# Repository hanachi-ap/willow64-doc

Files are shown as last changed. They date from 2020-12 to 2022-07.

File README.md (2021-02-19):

# willow64-doc
 In Japanese docments: [日本語での説明はこちら](README_JP.md)

## About Willow64 keyboard

The Willow64 is a split-type self-made keyboard featuring a key arrangement that gently fits natural finger movements.

Detailed article - [Introductory about Willow 64](https://coal.hatenablog.com/entry/2020/12/04/231923)

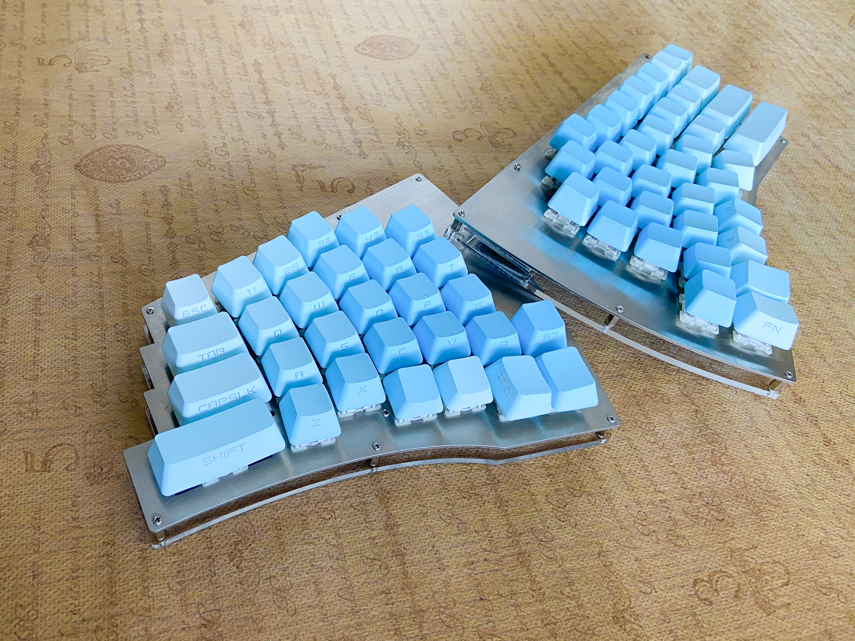
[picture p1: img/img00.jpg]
Willow64 willow64 keyboard
  

## Build guide

 [Willow64 keyboard Build guide](buildguide-willow64-r2.md)  (in Japanese) 

## QMK firmware

#### GitHub
  
  https://github.com/hanachi-ap/qmk_firmware/tree/willow64

#### QMK Firmware binary files.

  - [Default keymap (VIA enabled)](https://github.com/hanachi-ap/willow64-doc/releases/download/rev2.3.1/willow_willow64_via_default.hex)

    -  [Description about default keymap](./default-keymap.md)

  - [Test keymap](https://github.com/hanachi-ap/willow64-doc/releases/download/rev2.3.1/willow_willow64_buildtest.hex)

  - [Author's custom keymap](https://github.com/hanachi-ap/willow64-doc/releases/download/rev2.3.1/willow_willow64_via_hanachi.hex)

#### VIA json file

  - [VIA-wllow64.json](https://github.com/hanachi-ap/willow64-doc/releases/download/rev2.3.1/VIA_keymap_wllow64.json)

## Willow Layout

Willow Layout is open for the community to grow.
It is available under the Creative Commons license.

 [Willow Layout (PDF)](https://github.com/hanachi-ap/willow64-doc/blob/main/img/willow_layout_v1.pdf)  CC BY-SA 4.0 by Hanachi.

- For checking the layout before purchasing a product.
- For your new product development.
- For various research.

Feedback to the author would be a pleasure.

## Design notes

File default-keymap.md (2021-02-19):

# Description about default keymap

### layer 0 -- QWERTY layer

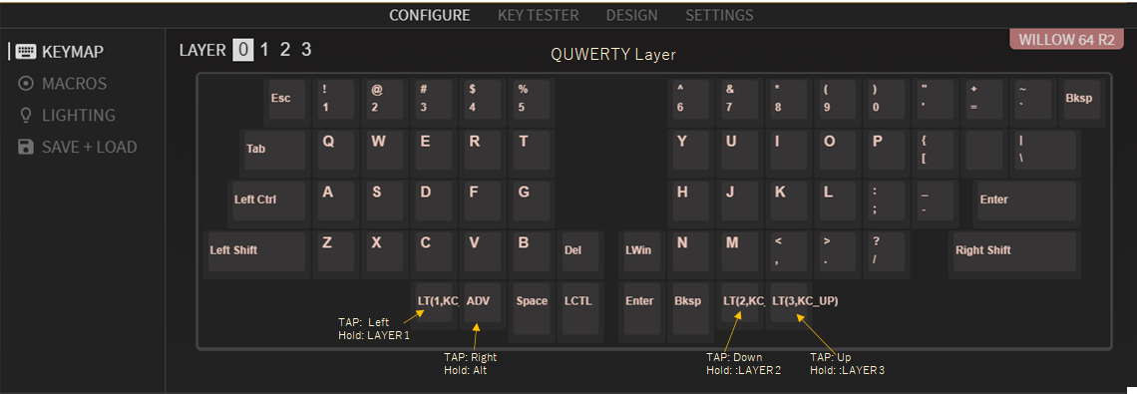
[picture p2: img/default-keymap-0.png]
Default keymap layer 0 Default keymap layer 0: QWERTY
  

### layer 1 -- Numpad layer

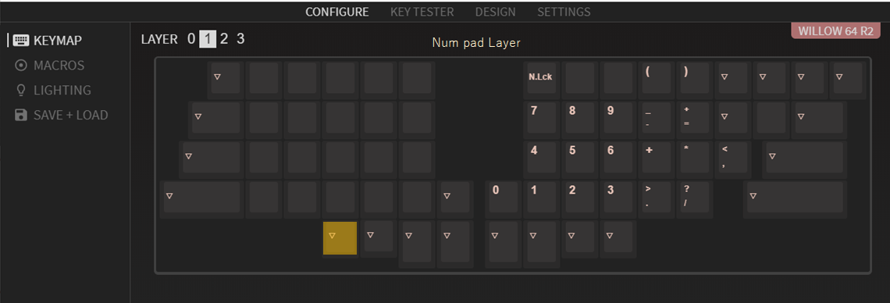
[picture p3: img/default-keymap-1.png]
Default keymap layer 1 Default keymap layer 1: Numpad
  

### layer 2 -- Function key layer

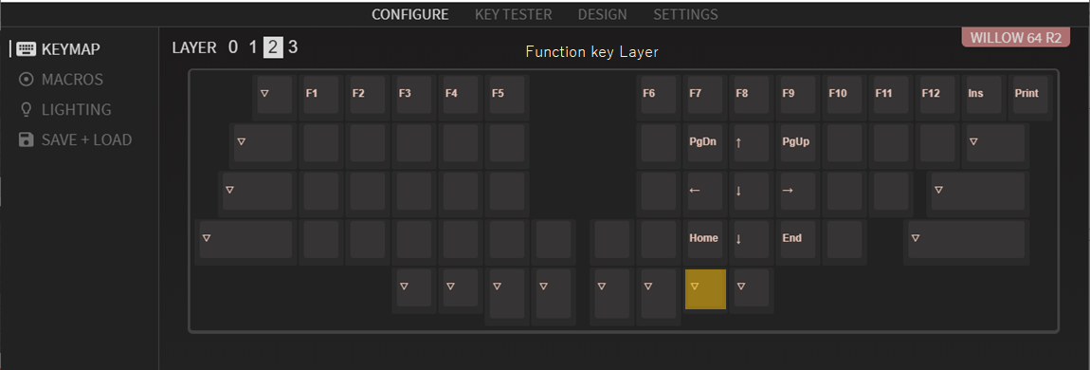
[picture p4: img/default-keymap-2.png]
Default keymap layer 2 Default keymap layer 2: Function key
  

### layer 3 -- System utility layer

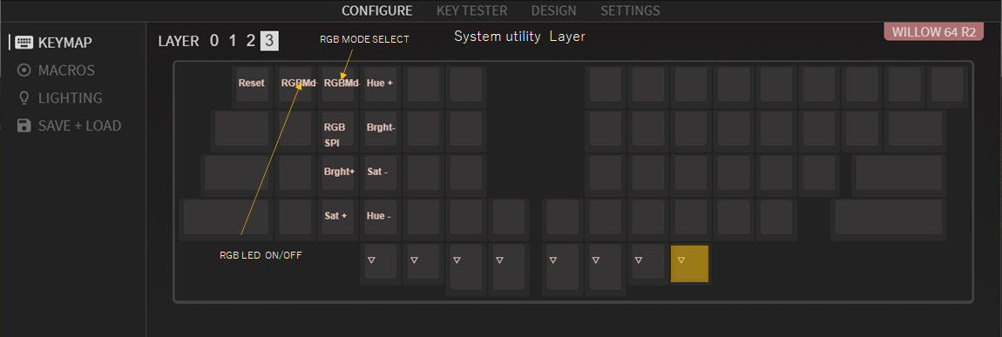
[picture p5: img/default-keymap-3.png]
Default keymap layer 3 Default keymap layer 3: system utilz
  

* * *
 ### VIA Enabled 
 'willow64_rev2_default.hex' has VIA enabeld.

- VIA is available here 
   
   - https://github.com/the-via/releases/releases/tag/v1.3.1
  
- VIA config file for willow64
  - https://github.com/hanachi-ap/willow64-doc/releases/download/releae01/VIA_keymap_wllow64.json

see also [ （初心者編）VIAを使ってキーマップを書き換えよう](https://salicylic-acid3.hatenablog.com/entry/via-manual)

### maniac
Keymap that the author regularly uses:
  - https://github.com/hanachi-ap/qmk_firmware/releases/download/rev02-1/willow64_rev2_hanachi_custom.hex

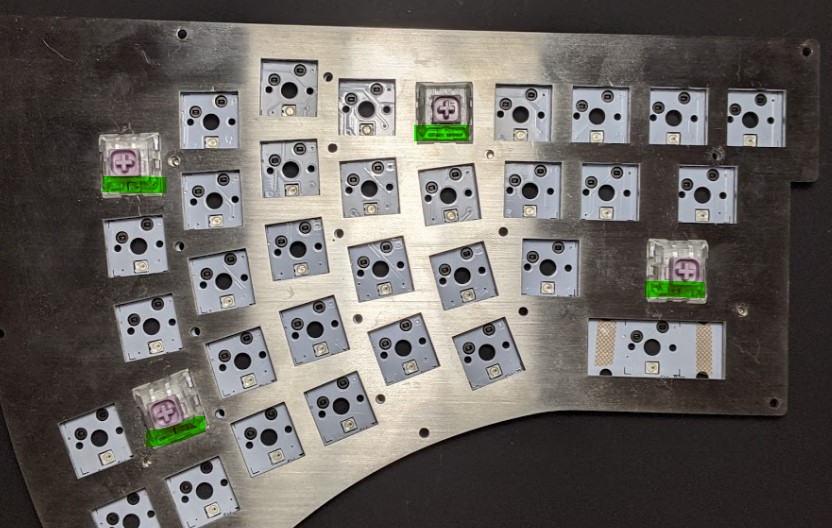
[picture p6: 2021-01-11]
img/switch-adjustment-right.jpg

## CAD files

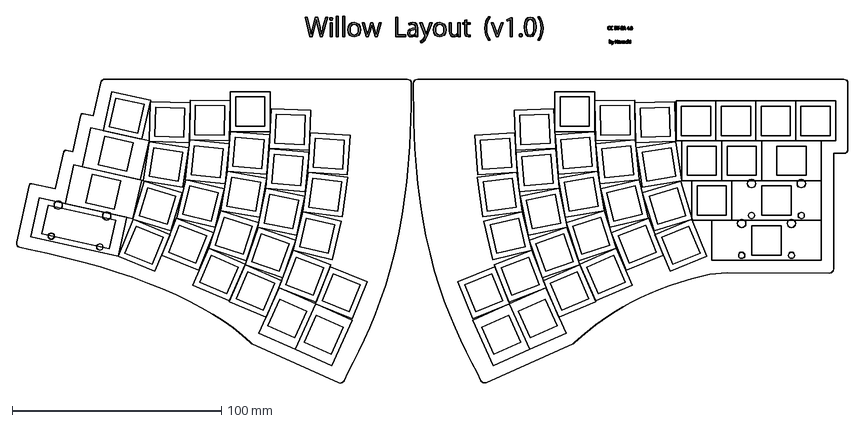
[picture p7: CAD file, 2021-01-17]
img/willow_layout_v1.dxf
397.8 x 175.6 mm

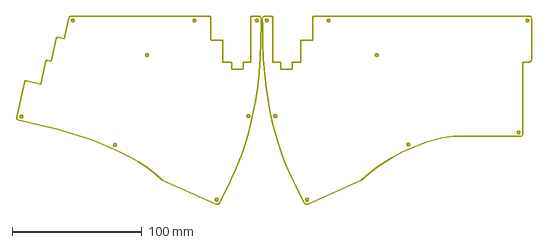
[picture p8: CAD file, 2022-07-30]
layout/willow64 bottom.dxf
397.8 x 145.6 mm

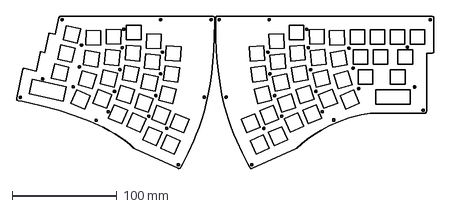
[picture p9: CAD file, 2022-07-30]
layout/willow64 top.dxf
397.8 x 145.6 mm

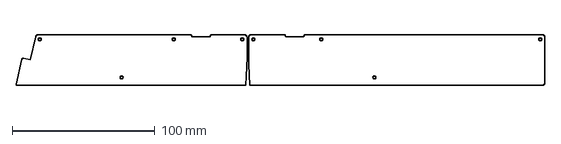
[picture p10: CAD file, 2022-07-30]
layout/willow64 cover.dxf
370.8 x 35.5 mm

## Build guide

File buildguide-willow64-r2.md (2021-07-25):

# Willow64 keyboard ビルドガイド

#### TOC

- [Willow64 keyboard ビルドガイド](#willow64-keyboard-ビルドガイド)
      - [TOC](#toc)
  - [はじめに](#はじめに)
      - [想定するユーザスキル](#想定するユーザスキル)
      - [このドキュメントでは言及しない内容](#このドキュメントでは言及しない内容)
  - [1.組み立て前の準備](#1組み立て前の準備)
    - [組み立てキット内容物](#組み立てキット内容物)
    - [組み立てキット以外に必要な部品](#組み立てキット以外に必要な部品)
      - [必ず必要な部品](#必ず必要な部品)
      - [必要に応じて揃える部品](#必要に応じて揃える部品)
    - [組み立てに必要なツール](#組み立てに必要なツール)
      - [必要なツール](#必要なツール)
      - [お好みに応じて用意するツール](#お好みに応じて用意するツール)
    - [ファームウェア書き込み環境の準備](#ファームウェア書き込み環境の準備)
      - [QMK Toolboxのダウンロードとインストール](#qmk-toolboxのダウンロードとインストール)
      - [Willow64用のファームウェアをダウンロード](#willow64用のファームウェアをダウンロード)
  - [組み立て手順](#組み立て手順)
    - [1.ProMicroのUSBコネクタ周辺の補強(オプション)](#1promicroのusbコネクタ周辺の補強オプション)
    - [2.ProMicroの取り付け](#2promicroの取り付け)
    - [3.TRRSジャックの取り付け](#3trrsジャックの取り付け)
    - [4.リセットスイッチの取り付け](#4リセットスイッチの取り付け)
    - [5.動作確認用ファームウェアの書き込み](#5動作確認用ファームウェアの書き込み)
    - [6.LEDのはんだ付け(オプション)](#6ledのはんだ付けオプション)
    - [7.ダイオードのはんだ付け](#7ダイオードのはんだ付け)
    - [8.スイッチソケットのはんだ付け](#8スイッチソケットのはんだ付け)
    - [9.キーの動作確認](#9キーの動作確認)
    - [10.スタビライザーの取り付け(Option)](#10スタビライザーの取り付けoption)
    - [11.ケースの組み立て](#11ケースの組み立て)
  - [2.キースイッチの取り付け](#2キースイッチの取り付け)
    - [13.キーキャップの取り付け](#13キーキャップの取り付け)
    - [14.本稼働用のファームウェアの書き込み](#14本稼働用のファームウェアの書き込み)
    - [以上で組み立ては完了です。お疲れさまでした](#以上で組み立ては完了ですお疲れさまでした)
  - [トラブル時の対処](#トラブル時の対処)
  - [参考情報](#参考情報)
    - [キーボードパーツショップ(日本)](#キーボードパーツショップ日本)
    - [はんだ付け技能](#はんだ付け技能)

## はじめに

本ドキュメントはWillow64を組み立てるための手順について記しています。

  > 対象機種:  Willow64 Assemly kit (PCB Rev.2.3  model SPA-2  スプリングピンヘッダ対応版)

  - 本キーボードの組み立て及び利用にはWindows PCもしくはMacが必要です。
      - このビルドガイドではWindows10を想定していますがMacについてもほとんど同じですので読み替えてください。

  - 本組み立てキットは、はんだ付けの工程が必要です。
     - 表面実装タイプの部品を取り扱う箇所があるため 組み立て難易度としてはやや高い部類になります。
    - はんだ付けについての様々な情報やテクニックについては本書末尾にまとめていますので、必要に応じて参照してください。

  - このドキュメントでは言及しない内容

    - はんだ付けの具体的な方法、関連技術など (必要に応じて末尾で紹介するサイトなどを参照してください)
    - キーマップのカスタマイズ方法 
    - QMK Firmwareの概要、導入、ビルド、コーディング方法
    - VIAの使い方
    - git、GitHubの使い方
    - キーボードの動作原理

## 1.組み立て前の準備
組み立てを始める前に、本章の内容を確認し準備が十分に整っていることを確認してから次に進んでください。

### 組み立てキット内容物
パッケージを開けたら、まず内容物が正しく揃っているかを確認します。

- PCB (プリント基板)  (右手 1個、左手 1個)

  電子部品を取り付けるプレートです。 左右で形状が異なります。写真を参考に左右と表裏を判別してください。
  (rev2.3では柳に蛙のシルクがプリントはありません)

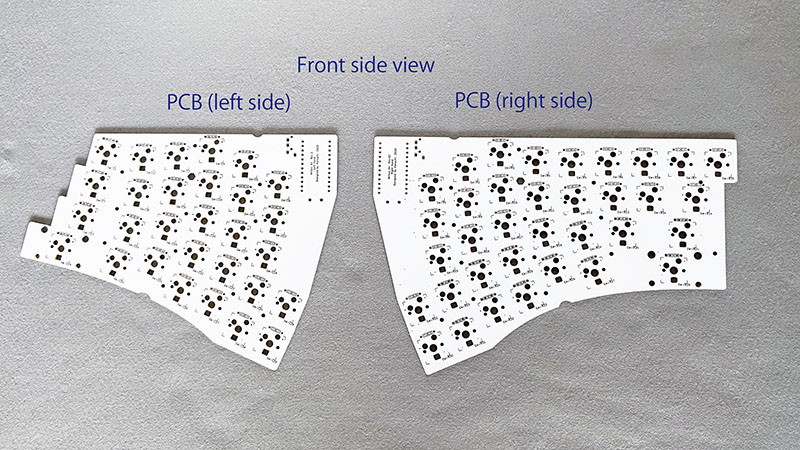
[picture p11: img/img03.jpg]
PCB front side
  
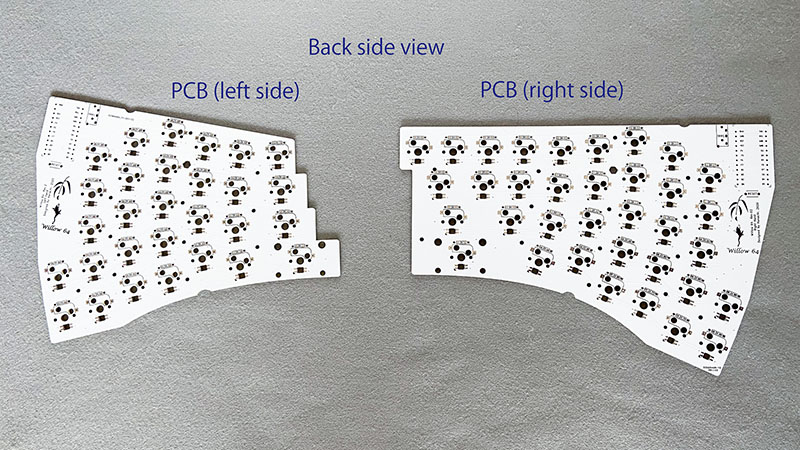
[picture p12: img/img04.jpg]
PCB back side
  

- トッププレート (右手 1個、左手 1個)
  
  キースイッチを取り付けるためのプレートです。左右で形状が異なります。

- ボトムプレート (右手 1個、左手 1個)
  
  キーボードの下面となるプレートです。左右で形状が異なります。

- アンダーカバー (右手 1個、左手 1個)
  
  ボトムプレートの開口している部分を覆うためのプレートです。左右で形状が異なります。
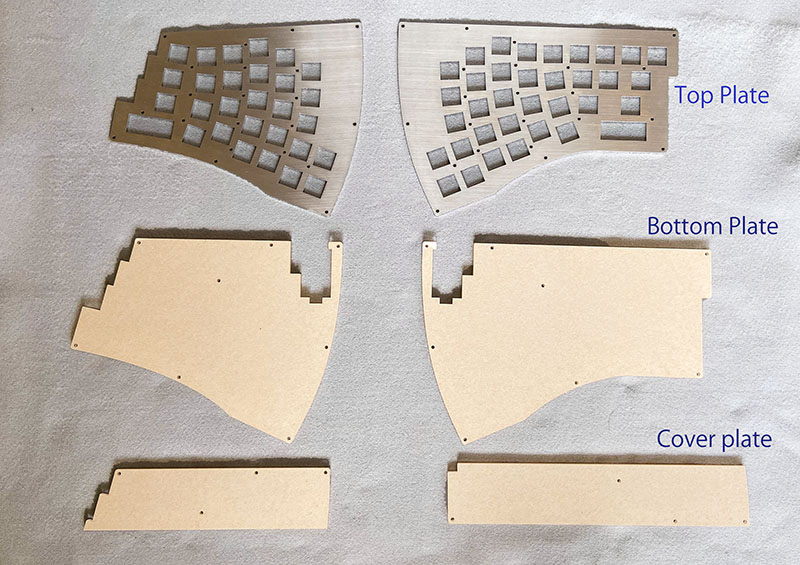
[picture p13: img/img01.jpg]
  
  アクリルプレートは組み立てる前に保護シートを剥がしてください。

- スイッチソケット (64個)

  キースイッチをはんだ付けすることなく、後から付け替え可能にするためのパーツです。

- ダイオード(SMD) (64個 +予備少々)
  
  電気信号を制御するためのパーツです。非常に小さいので紛失しないよう気をつけてください。

- タクトスイッチ  (2個)

  リセットスイッチとして使用するためのパーツです。

- TRRSジャック  (2個)

  分割された2つのキーボードを接続し一体として利用するためのケーブルを挿し込むパーツです。

- ネジ
  
  ネジは長さの異なる2種類あります。
  - ネジ(S) (32個)
  - ネジ(L) (16個)

- スペーサー
  
  スペーサーは長さの異なる2種類あります。
  - スペーサ(S)  (8個)
  - スペーサ(L)  (16個)
  
- ゴム足 (8個)
  
  キーボードの裏側に取り付けます

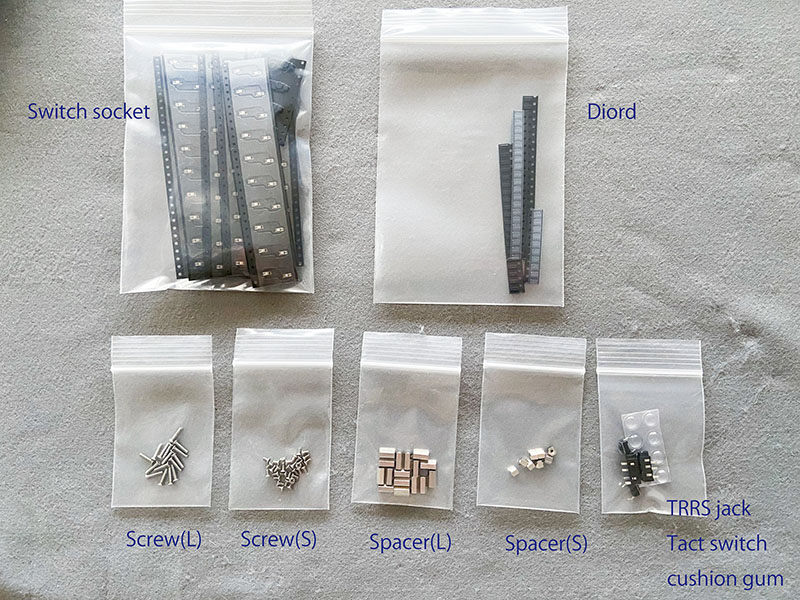
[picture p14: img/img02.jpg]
parts
  

### 組み立てキット以外に必要な部品
本組み立てキットに含まれる部品以外に、ユーザ自身で揃える必要がある部品があります。
組み立てを始める前に揃っていることを確認します。

なるべく日本の自作キーボード界隈でよく使われている部品を選定しているので
本書末尾のショップ一覧から入手可能です。

#### 必ず必要な部品
- ProMicro (2個)
  
  キーボードの頭脳として、左右一つづつ 合計2つ準備します。

- スプリングピンヘッダ もしくはピンヘッダ (4個)

  ProMicroをPCBに装着する際に取り外し可能とするパーツです。ProMicro 1つに対し2個、合計4個準備します。

 (スプリングピンヘッダ未対応ののPCB (rev2.2)を使用する場合は、通常の12ピンタイプのピンヘッダを準備してください)

- Cherry MK互換スイッチ  (64個)

  自作キーボードの醍醐味の部分なのでお好みで準備ください。
  Cherry MK互換 (3ピンもしくは5ピンタイプ)に対応しています。
  Kailhロープロファイルスイッチには非対応です。

- キーキャップ 

  お好みに応じて準備してください。ANSI USタイプが適合します。

  注記) 
    - Willow64 PCB (Rev.2)では、キーボード右上部分のBacksSpaceキーの部分は2Uタイプのキャップに非対応です。
    - その代わりに1Uのキーキャップが2個置ける配置となっていますのでご注意ください。

- TRRSケーブル (1本)
 
  左右に別れたキーボードを連結します。
  
  3極タイプ(3.5mmステレオミニプラグ 3極 オス-オス)も利用可能です。

- USB  Micro-Bケーブル (1本)

  パソコンとキーボードを接続するのに利用します。

#### 必要に応じて揃える部品

- スタビライザ(2U)  (2個)

  横に長いキーの動作を安定させるために使用します。  無くてもキーボードとしては機能します。
  
  安いスタビライザを使うとカチャカチャとうるさい場合があるのでお好みによって調達してください。

- LED (マイコン内蔵RGB LED SK6812MINI-E) (64個)

  各キーを下側から光らせるために使用します。  無くてもキーボードとしては機能します。
  
  LEDを実装すると  キーボードを光で演出する、レイヤ動作モードを光で知らせる、CAPSLOCKやNUMLOCK状態を表示する、といったことが可能となります。

- エポキシ接着剤

  ProMicroのUSBコネクタは強度が弱いことが知られています。コネクタ周辺を補強するためにエポキシ接着剤を使用します。
  100円ショプなどで2液タイプのものが手に入ります。

### 組み立てに必要なツール
電子工作の基本的なツールを用意します。

#### 必要なツール
- はんだごて
- 糸はんだ
- はんだ付けの周辺グッズ
  - コテ台、スポンジ、作業マット、吸煙ファン、等
- ピンセット and/or 逆作用ピンセット
- 精密ドライバ(プラス No.0)

#### お好みに応じて用意するツール 
- ハンダ吸い取り線
- フラックス
- フラックス洗浄剤
- ラジオペンチ
- マスキングテープ
- ヤスリ
- テスタ(マルチメータ)
### ファームウェア書き込み環境の準備

キーボードの頭脳となるProMicroにファームウェアをPCから書き込むための環境を予め準備します。

#### QMK Toolboxのダウンロードとインストール
 QMK Toolboxは、ファームウェアをマイコン(ProMicro)へ書き込むために必要となります。
 (既に環境がある方はこの作業は不要です)

 - 下記から QMK Toolboxをダウンローして自身のPCへインストールします。

    https://qmk.fm/ja/toolbox/

 - インストール方法はサイトの情報に従ってください。必要に応じてドライバもインストールします。

#### Willow64用のファームウェアをダウンロード
 - Willow64のビルド済みファームウェアを下記のURLからダウンロードしPCへ保存しておきます。

   https://github.com/hanachi-ap/willow64-doc

    - [default keymap](https://github.com/hanachi-ap/willow64-doc/releases/download/rev2.3.1/willow_willow64_via_default.hex)
    - [組立時のテスト用keymap](https://github.com/hanachi-ap/willow64-doc/releases/download/rev2.3.1/willow_willow64_buildtest.hex)
    - [作者常用のおすすめ](https://github.com/hanachi-ap/willow64-doc/releases/download/rev2.3.1/willow_willow64_via_hanachi.hex)

## 組み立て手順
- 組み立て手順のインデックス
    - [1.ProMicroのUSBコネクタ周辺の補強(オプション)](#1promicroのusbコネクタ周辺の補強オプション)
    - [2.ProMicroの取り付け](#2promicroの取り付け)
    - [3.TRRSジャックの取り付け](#3trrsジャックの取り付け)
    - [4.リセットスイッチの取り付け](#4リセットスイッチの取り付け)
    - [5.動作確認用ファームウェアの書き込み](#5動作確認用ファームウェアの書き込み)
    - [6.LEDのはんだ付け(オプション)](#6ledのはんだ付けオプション)
    - [7.ダイオードのはんだ付け](#7ダイオードのはんだ付け)
    - [8.スイッチソケットのはんだ付け](#8スイッチソケットのはんだ付け)
    - [9.キーの動作確認](#9キーの動作確認)
    - [10.スタビライザーの取り付け(Option)](#10スタビライザーの取り付けoption)
    - [11.ケースの組み立て](#11ケースの組み立て)
    - [12.キースイッチの取り付け](#12キースイッチの取り付け)
    - [13.キーキャップの取り付け](#13キーキャップの取り付け)
    - [14.本稼働用のファームウェアの書き込み](#14本稼働用のファームウェアの書き込み)

NOTE
 - パーツは、全てPCBの裏面に配置します。PCBの表面にはパーツが配置されることはありません。
 - はんだ付けはパーツの種類ごとに、PCB裏面から行うか表面から行うか分かれるので手順に従ってください。

### 1.ProMicroのUSBコネクタ周辺の補強(オプション)
下記作業を、2つのProMicroに対して行います。

- ProMicroのUSBコネクタ部分をエポキシ樹脂で強化します。
- エポキシ樹脂説明書の指示通りに調合し、爪楊枝の先などで慎重にUSBコネクタ周辺に盛り付けます。
- 樹脂が硬化するまで安静にします。

NOTE
- USB端子の中やスルーホールに液がに侵入しないよう注意ください。

### 2.ProMicroの取り付け

下記作業を、2つのProMicroに対して行います。

- PCBの裏側を上向きにします
- スプリングピンヘッダの足の長い方をPCBの裏側からスルーホールへ差し込みます。
- ProMicroの部品が実装してある面が内側に隠れるような向き(平らな面が見える向き)でピンヘッダに差し込みます

  左右2列づつホールが並んでいますが、右側の列(黒い枠線で囲ってある側)を使用します。
  (左側の列のホールは将来の拡張用で現時点では動作しません)

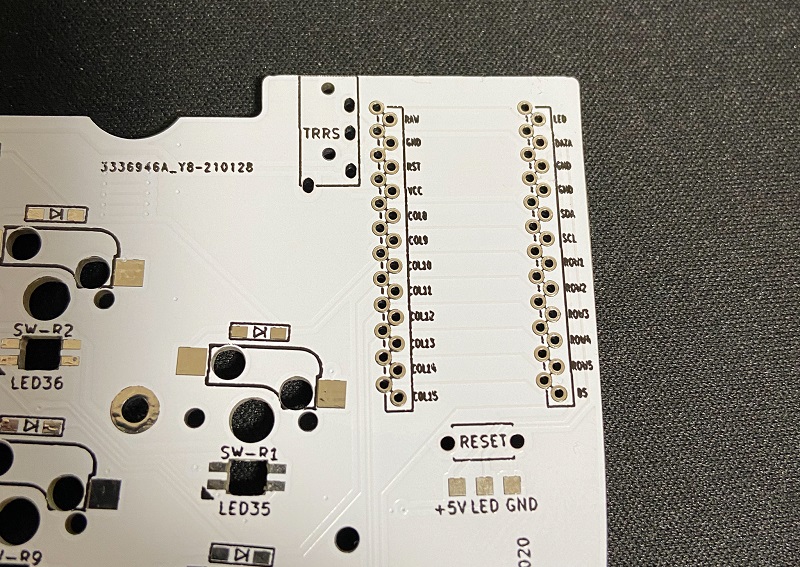
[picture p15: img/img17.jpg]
   

- ProMicro側のピンヘッダをはんだ付けします。

NOTE 
  - PCB側のピンヘッダははんだ付けしません。はんだ付けするのはProMicro側だけです。
  - ProMicroの表裏を間違えるとリカバリが非常に大変ですのではんだ付けの前に向きに注意ください。

### 3.TRRSジャックの取り付け
下記作業を、左右のPCBに対して行います。

- TRRSジャックをPCBの裏側からシルクに合わせて取り付けます。
- PCBの表側からはんだ付けします。

### 4.リセットスイッチの取り付け
下記作業を、左右のPCBに対して行います。

   - タクトスイッチをPCBの裏側からシルクに合わせて取り付けます。
   - PCBの表側からはんだ付けします。

NOTE
 - タクトスイッチは向きの指定はありません。

ここまでの作業イメージ

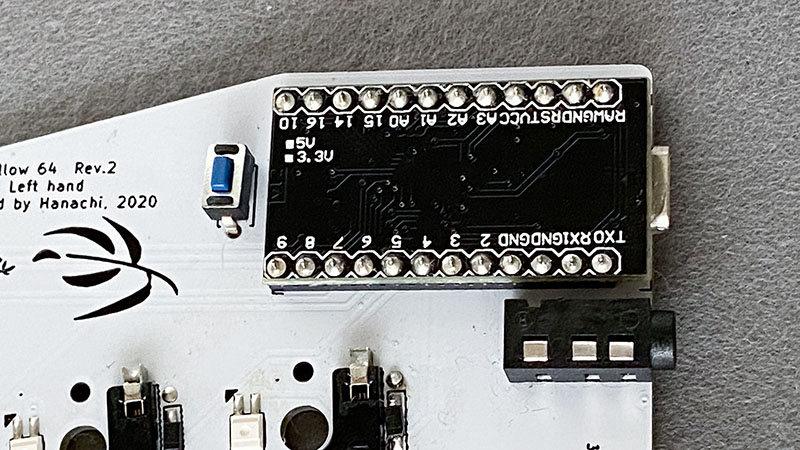
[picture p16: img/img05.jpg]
  

### 5.動作確認用ファームウェアの書き込み

キースイッチおよびLEDの動作確認用のファームウェアをProMicroに書き込みます。

- PC側のQMK Toolboxで書き込みを準備します
  - PC上で QMK Tookboxを起動します
  - Openボタンをクリックし、入手した動作確認用firmwareファイルを指定します。
  - Auto-Flashの部分をチェックします

- 左右それぞれのキーボード側に書き込みを行います
  - USBケーブルでPCとProMicroを接続します。
  - PCB上のリセットスイッチ押します。
  - QMK Toolbox上で書き込みログが表示されるので正常に完了することを確認します

### 6.LEDのはんだ付け(オプション)

下記作業を2枚のPCB 合計64箇所に対して行います。

  - PCBの裏側から四角い穴に合わせてLEDをはめ込みます。
    - この時、LEDの発光面がPCBの表側に来る向きにします。
    - PCBにプリントされた三角のとLEDの足が短い端子が合うように方向を合わせます。
  - PCBのランドとLEDの足 4箇所をはんだ付けします。 

NOTE
  - LEDをはんだ付けする際はフラックスを塗布するとハンダが乗りやすいです。
  - LEDの裏表、LEDの向きを間違うとLEDは発光しません。
  - LEDは高温に弱く長時間はんだごてを押し当てると破損するため、なるべく手早くはんだ付けするよう注意します。
  - LEDはチェーンのように連鎖した接続されています。途中で不良があると、それ以降のLEDは全て動作しないので注意ください。
   LEDは次のように接続されます。 (Rev2.3以降はPCB裏面にLED番号が印刷してあります) 
```` 
/* LED POSITION
    03, 04, 11, 12, 21, 22,            35, 36, 45, 46, 53, 54, 60, 61, 63, \
    02, 05, 10, 13, 20, 23,            34, 37, 44, 47, 52, 55, 59,   62,   \
    01, 06, 09, 14, 19, 24,            33, 38, 43, 48, 51, 56,       58,   \
    00, 07, 08, 15, 18, 25, 28,    29, 32, 39, 42, 49, 50,           57,   \
                16, 17, 26, 27,    30, 31, 40, 41                          \
*/
````

### 7.ダイオードのはんだ付け

下記作業を左右のPCB 合計64箇所に対して行います。
  - ダイオードの向きとPCBのシルクを合わせて、ダイオードの両端をはんだ付けします。
    - PCBのランドの片方に予備ハンダを盛ります
    - 予備ハンダを溶かしつつダイオードを所定の位置に送り込みます。
    - 反対側をはんだ付けします
    - 予備ハンダをした方をもう一度はんだ付けします

NOTE 
 - ダイオードには極性があります。
   - ダイオードに薄く線が引かれている方(カソード)と、PCBにシルクで線が引かれている方向を合わせるようにします。
   - ダイオードの向きに間違いがあるとそのキーは反応しなくなるので注意ください。
 - フラックスを塗布すると作業性が向上します。
 - 部品の浮きが無いように注意ください。
 - ダイオードは非常に小さいため紛失しないよう注意ください。
 - ダイオードのはんだ付けのテクニックについては末尾の情報を参考にしてください。
  
### 8.スイッチソケットのはんだ付け

下記作業を左右のPCB 合計64箇所に対して実施します。

  - スイッチソケットを差し込みます。
    - PCBのホールに干渉しないよう向きに注意します。
  - 2箇所をはんだ付けします。

NOTE
- 部品の浮きがないように注意ください。

ここまでの作業イメージ

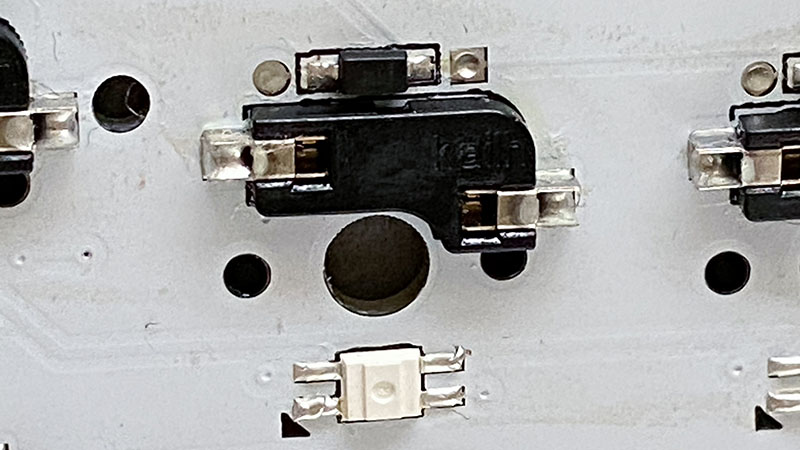
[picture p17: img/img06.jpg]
  

はんだ付けの作業はここまでです。 
### 9.キーの動作確認
ケースを組み立てる前に、各キーが正しく反応するか電気的な動作確認をこの段階で行うことを推奨します。
- PCのブラウザで次の動作確認用のURLを開き、ピンセットのさきなどをスイッチソケットに差し込み動作するか確認します。  
   https://config.qmk.fm/#/test

### 10.スタビライザーの取り付け(Option)

スタビライザーを使用する場合は、ケースを組み立てる前のこの段階でPCBへ取り付けます。

### 11.ケースの組み立て
下記作業を左右それぞれのキーボードに対して行います。

- ネジ止めする前にアクリルプレートの保護シートを剥がします。

- 左右のトッププレートに表側からネジ、裏側からスペーサを取り付けます
- プレートの表側からネジ(S)を差し込み、裏側にスペーサ(S)、スペーサ(L)をネジ止めします。
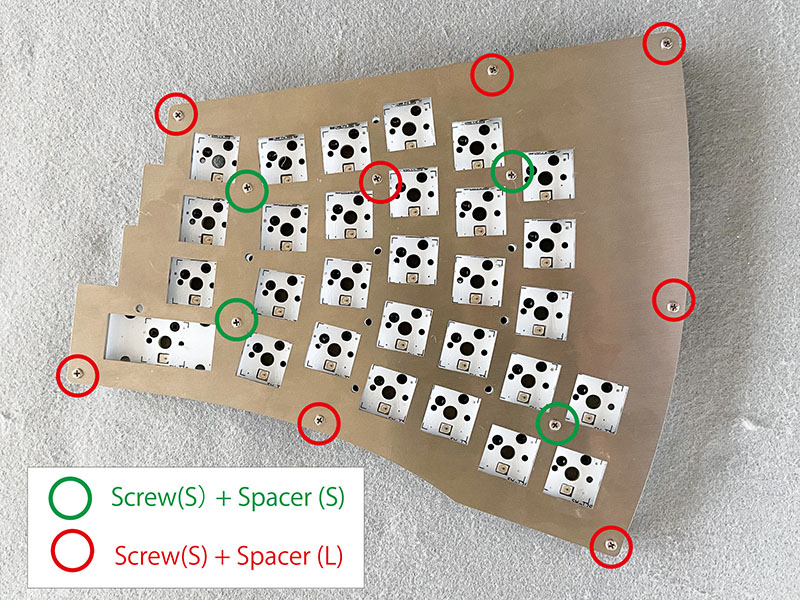
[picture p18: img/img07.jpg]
  
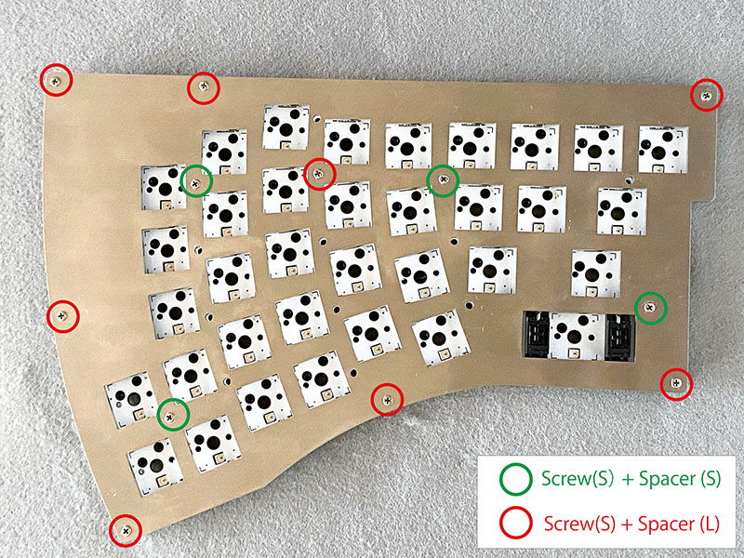
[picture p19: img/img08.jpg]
  

- PCBをあわせ、PCB裏側からネジ(M2 L3)で結合します。

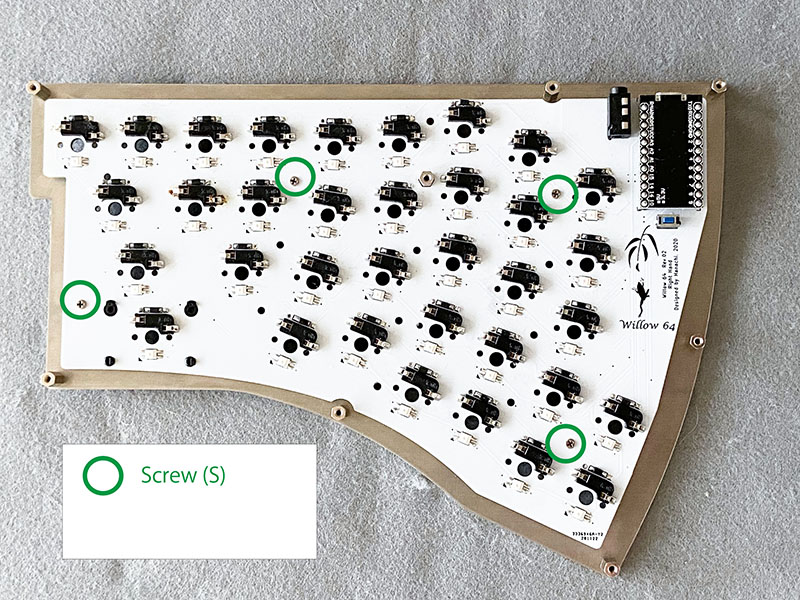
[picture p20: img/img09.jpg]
  
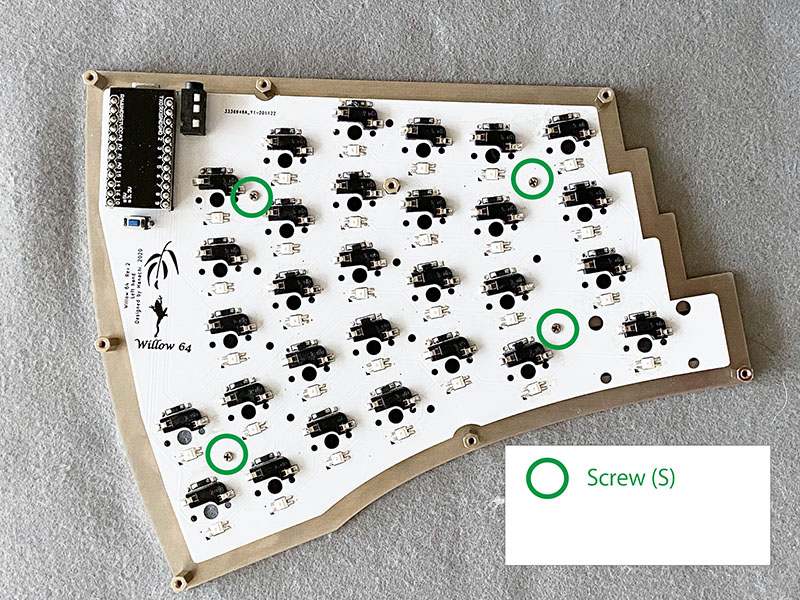
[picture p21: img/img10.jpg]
  

  NOTE
    - ネジは最初は緩く締めておき全体の組み立てができた後に本締めするようにします。
    - 何個かのスイッチを取り付けた状態で本締めをすると全体的な微妙なズレが生じることがなくなります。

- ボトムプレートと更にアンダーカバープレートを合わせ、写真を参考に ネジ止めします。
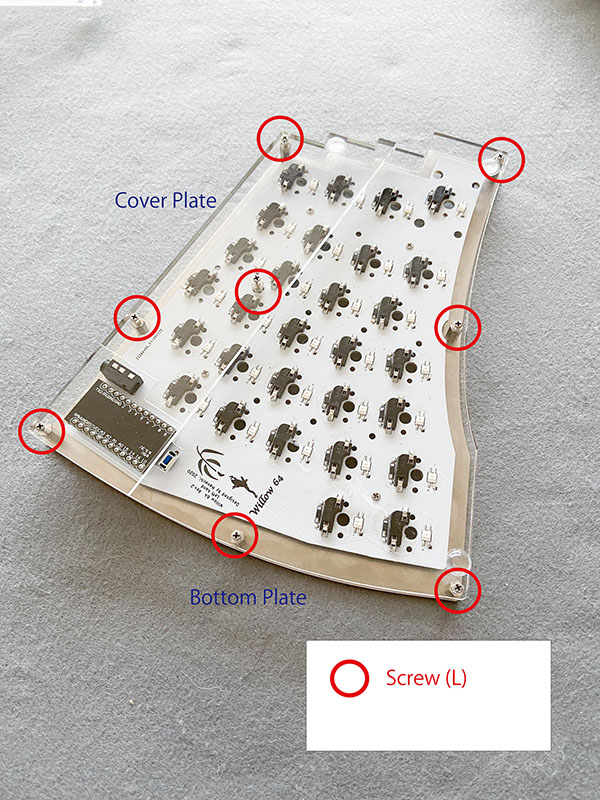
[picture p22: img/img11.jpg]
  
- ゴム足を4箇所に貼り付けます。

## 2.キースイッチの取り付け

キースイッチを取り付けます。

NOTE
- キースイッチを取り付ける際にはまっすぐ上から慎重に差し込むようにします。
- スイッチのピンは曲がりやすいので注意してください。  ピンが曲がったまま無理矢理取り付けるとそのキーは反応しなくなります。
- ピンが曲がってしまった場合でも、一度引き抜いてラジオペンチの先端で慎重に伸ばせばリカバリ可能です。
-  輸送や保管の都合ですでに曲がっている場合もありますので、取り付け直前に1つ1つ確認することをお勧めします。

### 13.キーキャップの取り付け

- 下図を参考にキースイッチにキーキャップを取り付けます。
  
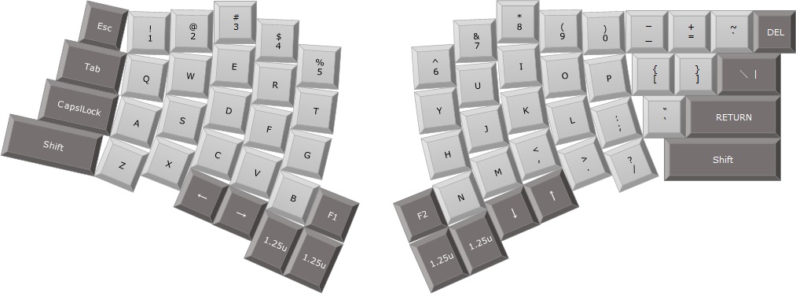
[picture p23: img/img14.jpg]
  

以上で組み立ては完成です。
### 14.本稼働用のファームウェアの書き込み

下記の作業を左右のキーボードそれぞれに対して行います。

- PC側でQMK Toolboxを起動し、本番用ファームウェアをオープンします。
- QMK ToolboxのAuto-Flashをチェックします
- USBケーブルを接続します。
- リセットスイッチを押してファームウェアを書き込みます。

完成した後は次のようにケーブルを刺します。
  - 左右のキーボードをTRRSケーブルで接続します
    (TRRSはホットプラグに非対応なので抜き差しする際はUSBを外してください)

  - 左手側のキーボードにUSBケーブルを接続します

### 以上で組み立ては完了です。お疲れさまでした

* * *
## トラブル時の対処
ありがちなトラブルとその対処について記します。

- 特定のキーが反応しない
   
  大抵の場合は下記の原因が考えられるので落ち着いて調べます
  - キースイッチのピン(足)が折れ曲がっていないか
  - ダイオードの向きが逆でないか
  - ダイオードのはんだ付け不良はないか
  - キーソケットのはんだ付け不良はないか
  - そもそも、そのキーにキーコードが割り当てられていない(レイヤー切り替え等)

- どのキーも反応しない
    - PCとキーボードが正しくUSBで接続されているか。通電するとProMicro表側に実装されたLEDが点灯します。
    - 左右どちらのProMicroにも正しくファームウェアが書き込まれているか。
    - ProMicroのはんだ付け不良はないか
    - ProMicroのピンヘッダが曲がっていないか

- ダイオードを無くしてしまった
  - 通販でも入手可能です。
     (高速スイッチング・ダイオード　１Ｎ４１４８Ｗ)を購入してください。

- トッププレートの穴が小さくてキースイッチが入らない、もしくは緩くて抜け落ちる
  - スイッチはメーカやモデルによって微妙にサイズが異なるため、加工精度(公差)を
    考慮して少し小さめにしてあります。
  - 全く入らない場合は穴の方をヤスリで少し削ってください。
  - 逆に抜け落ちるような場合はプレート裏側からグルーガンで固定してください。
    
## 参考情報

### キーボードパーツショップ(日本)

自作キーボードの代表的なショップを列挙します(順不同)。前述のみ立てキット以外に必要な部品は下記ショップでほぼ揃います。

- 遊舎工房 (https://yushakobo.jp/)
- TALP KEYBOARD (https://talpkeyboard.stores.jp/)
- ゆかりキーボードファクトリ (https://eucalyn.shop/)
- 秋月電子通商 (https://akizukidenshi.com/catalog/default.aspx)

### はんだ付け技能
下記以外にも様々なテクニックやノウハウが公開されているので、検索サイトで調べるようにしてください。

- [電子工作のコツ/はんだ付け ](https://article.murata.com/ja-jp/article/soldering)村田製作所
- [ハンダ付け職人のはんだ付け講座](https://godhanda.co.jp/blog/category/handakouza/soldering%E3%80%80guide/)ゴッドはんだ株式会社
- [表面実装部品（SMD）のはんだ付け](https://www.kogadenshi.co.jp/%E5%8D%8A%E7%94%B0%E4%BB%98%E3%81%91%E3%83%86%E3%82%AF%E3%83%8B%E3%83%83%E3%82%AF/%E8%A1%A8%E9%9D%A2%E5%AE%9F%E8%A3%85%E9%83%A8%E5%93%81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) 株式会社古賀電子

以上

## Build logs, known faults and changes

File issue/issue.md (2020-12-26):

Willow64 Keyboard assembly kit Issue.

- 対象:
   - 型式  Willow64 assembly kit PCB R2 model SPA-1
   - 頒布時期  2020年12月 
   - 最終更新 2020/12/26 

- issue 01

  PCB裏面側ののProMicroコンスルーを挿入するホール周辺のメッキがありません。

  このためProMicroとPCBの接触が悪くなり導通しないピンが生じる恐れがあります。

  テスタで導通しないこピンが確認できた場合はコンスルーのピンを少し曲げるなどして接触を増やすようお願いします。
  
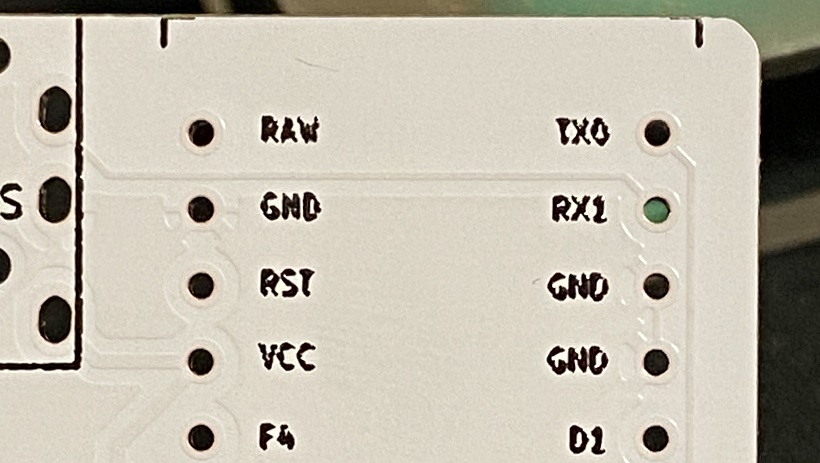
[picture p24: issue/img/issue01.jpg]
  

- issue 02

  TRRSケーブルのスリーブが太いものをご使用の場合、ケースと干渉してジャックに差し込めない場合があります。
 
  (現状確認できている範囲では、スリーブの直径6.9mmのケーブルは問題ありませんが、9.3mmのケーブルは干渉しています)
  
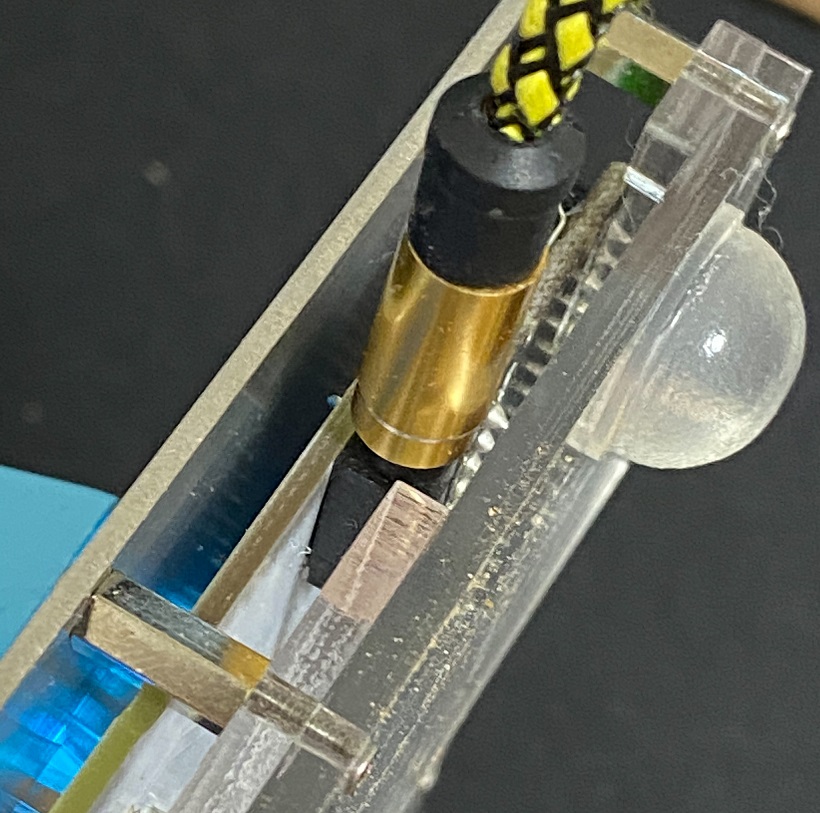
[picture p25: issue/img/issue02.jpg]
  

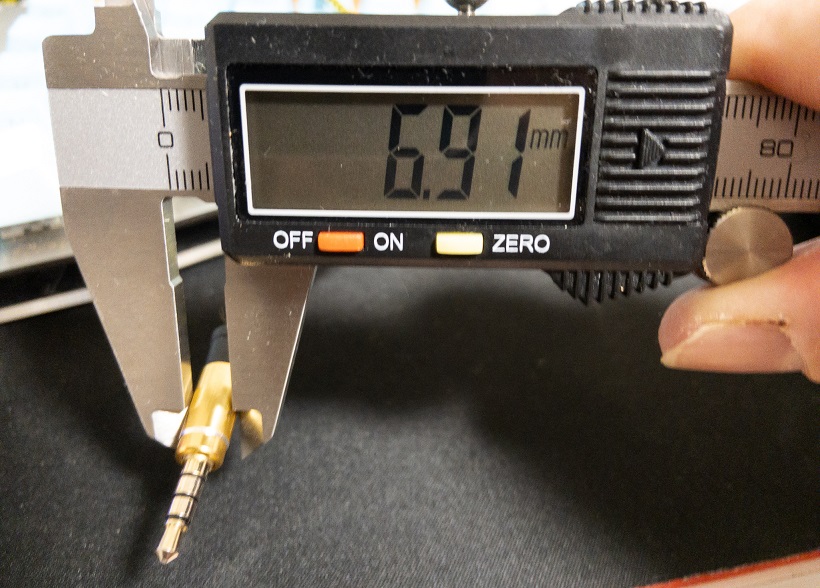
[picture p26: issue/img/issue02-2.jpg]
  

- issue 03
  
  右手側のアクリル製カバープレートの一部のコーナー丸め角(R)が、ボトムプレートと僅かに異なっている箇所があります。
  
  美観的な面以外には機能上の問題はありません。

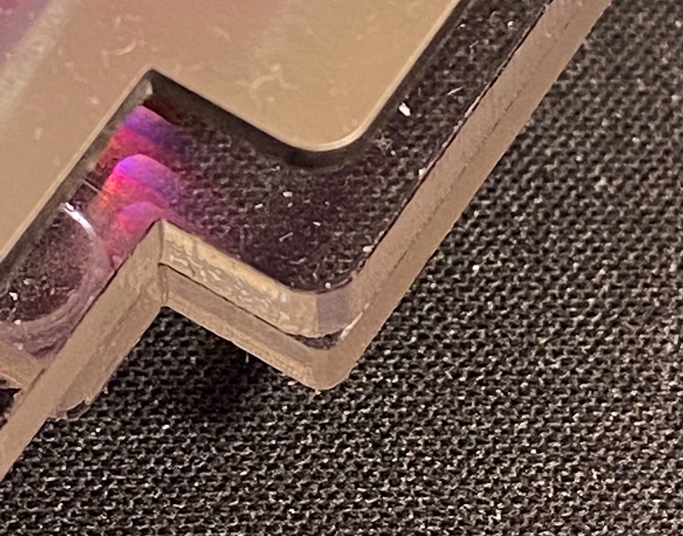
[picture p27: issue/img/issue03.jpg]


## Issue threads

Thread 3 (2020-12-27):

入らないTRRSケーブルの詳細

koron, 2020-12-27:
https://twitter.com/haswellep/status/1343220957465387009

> これは設計を見直さなきゃいけない範囲なので～ちなみにケーブル側の直径わかりますか

次の写真のケーブルです。計測は写真内のシンワのノギスです。

位置 | 入手元 | 挿入可否 | 直径 | 備考
---|---|---|---|---
左上 | [遊舎工房](https://yushakobo.jp/shop/trrs_cable/) |  可 | 6.0mm |
右上 | [Amazon](https://www.amazon.co.jp/gp/product/B01MXCKHAM/) | 条件次第で可 | 7.2mm/8.7ｍｍ | 円形ではない。短辺を少し削るように入る
左下 | [Amazon](https://www.amazon.co.jp/gp/product/B07SL84NM2/) | 不可 | 9.0±0.1mm |
右下 | [Amazon](https://www.amazon.co.jp/gp/product/B07G1VGY29/) | 不可 | 8.8mm |

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

hanachi-ap, 2020-12-28:
カバープレートとTRRSケーブルが干渉する問題点を確認しました。
確認時のケーブルのサンプル不足でした。頂いた情報は非常に参考になります。
本件についてはPCB及びプレート両面での対処が必要となるため、時期リビジョンにて対応を検討します。

koron, 2020-12-28:
現状でもこういうの買えば好きなケーブルが付けられそうです。

っていうか買ったので後日レポートしますw

https://www.amazon.co.jp/dp/B016AHYRNW/

koron, 2020-12-30:
↑の商品、完璧でした。以下のように、コネクタを延伸してどんなケーブルでも繋がります。

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

これを使った状態で全キーが機能するところまで確認しました。

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

ぶっちゃけコレを前提にするとデザインの幅が広がるかもしれませんねw

Closed 2021-02-19.

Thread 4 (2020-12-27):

右側のスタビライザを付けないように案内する

koron, 2020-12-27:
右側のスタビライザのキースイッチがスタビライザの中心にありません。
そのためスタビライザーを付けてしまうと
2u(以上の)キーキャップが取り付けられないか
無理矢理取り付けた場合はキーキャップの動作が不安定になります。
取り急ぎビルドガイドなどで
右側のスタビライザーを付けないように
案内したほうが良いかと思います。

---

以下、写真で。

スタビライザーの軸に合わせると、キースイッチの軸が若干左に寄っている。
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

キースイッチの左の隙間が右よりも明らかに狭い。
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

シルク印刷も左に寄っている。
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

装着しているスタビライザーは遊舎工房で購入した [MXスイッチ スタビライザー](https://yushakobo.jp/shop/a0500st/) の黒、2Ux1 です。

hanachi-ap, 2020-12-28:
報告頂いた問題を確認しました。

手元のスタビライザとキーキャップの組み合わせでは大きな違和感を感じていなかったための見逃しです。

PCBの修正が必要なため時期リビジョンでのしゅうせいを検討します。
暫定対処として現行バージョンでの制限事項をドキュメント化します。

Closed 2021-02-19.

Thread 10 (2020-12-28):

buildtestファームでは右側のLEDのラスト6個が点かないことがある

koron, 2020-12-28:
biuldtestファームを使っていると、選択される点灯パターン(例:数秒ごとにR→G→Bと色が変換するやつ等)によっては、右側をUSBに直接接続(master)にした際に最後の5個、すなわち58～63番のLEDが点灯しません。そのためLEDを正しく接続できていてもできていないと勘違いしてしまうことがあります。

なおこの場合でもslaveとして繋ぐ≒左側をUSBに繋ぎ右側はTRRSケーブルでつなげば全灯点灯します。

ご存じの通りRGB LEDは信号線上に1個目からn個目までの点灯データを流しています。masterの左側は29個のLEDがあるのに、右側が35個であることからこの差の分のLEDが点灯していないのだと推測されます。

この挙動は組み立て時テスト用のファームとしてはふさわしくありません。必ず特定のパターンを再生し、加えてパターンはmasterのLEDデータを参照しないものを選ぶべきです。

---

以下ざっくり経緯を。

初回まっさらなPicoMicroにビルドテストファームを焼いたときはRGB Swarmあたりのアニメーションパターンが再生され、それでは右側masterでも58～63番は点灯しました。

しかし一度デフォルトファームを焼いていろいろやってから、再びビルドテストファームを焼いた際にはRGBの切り替わりテストパターンになり、58～63番が点灯しなくなりました。(私はコレを壊したと勘違いしてLEDの交換作業でスったもんだした)

おそらくEEPROMを見てテストパターンを決めているのでしょう。で、このRGBテストパターンはmasterのLEDデータを見てその数29個分しか点灯データを送らないと推測されます。しかし右側には35個のLEDがありますから最後の6つ58～63番が点灯しません。

hanachi-ap, 2020-12-28:
報告の問題点について理解しました。無駄たお手数をおかけしてしまってすいません

テスト用に、左右別々のhexを用意する形で修正します。
(キーコードにつては同様の問題を認知し修正していましたが、LEDは横並び確認漏れ、というやつです)

> 初回まっさらなPicoMicroにビルドテストファームを焼いたときはRGB Swarmあたりのアニメーションパターンが再生され

実はこちらのほうが原因がわかっていません。初期化コードで    rgblight_mode(RGBLIGHT_MODE_RGB_TEST);
を入れているので。時々VAIが予期せぬ副作用を起こす時があるのでdefault keymapがはじめからVIA対応というのも含め見直してみます。

hanachi-ap, 2020-12-28:
暫定対処として少し強引なソース修正で解消しました。

Releaseフォルダにはコンパイル済みファームを置き換えしてあります。

koron, 2021-01-01:
> Releaseフォルダにはコンパイル済みファームを置き換えしてあります。

Release フォルダというのは https://github.com/hanachi-ap/qmk_firmware/releases/tag/rev02-1 これであっていますでしょうか?

> > 初回まっさらなPicoMicroにビルドテストファームを焼いたときはRGB Swarmあたりのアニメーションパターンが再生され
>
> 実はこちらのほうが原因がわかっていません

https://github.com/hanachi-ap/qmk_firmware/blob/ac15e9d8b8ed198613af6f02dc8660be5e4d41e9/keyboards/willow64/rev2/keymaps/hanachi_custom/keymap.c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

これじゃないですかね? なんか僕が忘れてる手順があってこのアニメーション設定がEEPROMに書き込まれてて…みたいな。

koron, 2021-01-01:
> Release フォルダというのは https://github.com/hanachi-ap/qmk_firmware/releases/tag/rev02-1 これであっていますでしょうか?

ここに置いてあった buildtest を右側に書き込んでマスターにして起動したところ、すべてのLEDが点灯し正しく動作することを確認しました。

ありがとうございます!

Closed 2021-01-01.

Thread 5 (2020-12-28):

PCBにあるキースイッチの補助足用の穴の間隔が狭い

koron, 2020-12-28:
PCBマウント5ピンの仕様のキースイッチを使うと補助足用の穴の間隔が若干狭くて正常には取り付けられません。そのためPCBとトッププレートの間に力がかかりキースイッチが抜けやすくなります。(次の写真を参照)

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

加えてこのように取り付けてしまうと次の写真のようにキースイッチの補助足を削ることになってしまいます。(左側のスイッチの右側の足が削れている。右側はPCBに差してない正常なもの)

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

写真のキースイッチは [Gateron Silentスイッチ](https://yushakobo.jp/shop/a02gs/) です。このスイッチで補助足と主足との隙間を計測したら 2.3mm でした。一方でPCBのほうは 2.1～2.2mm でした。

参考までにCorne Cherry v3での設置状況も共有します。こちらは [Gateronスイッチ](https://yushakobo.jp/shop/a0200ga/) ですが、PCBとスイッチのハウジングに隙間はなく、補助足の先端がPCBよりも下に出ているのが見てとれます。

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

koron, 2020-12-28:
書き忘れ。対象のPCBは左右両方です。後程、ちょっと穴を削って広げてどうなるかやってみます。

koron, 2020-12-28:
[ヤスリ](https://www.hobby-wave.com/products/ht424/) で削ってみました。両穴の外側と下側を10コスりくらい、右側の内側を数コスり。写真のSW-L22が削り済みでスムーズに入るようになります。SW-L26は削っていないので比較対象に。

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

hanachi-ap, 2020-12-28:
報告いただいた問題について承知しました。
足が削れるほどの干渉は確認できていなかったため手持ちのスイッチで現在再現性を確認しています。

基本、キーボード設計のオーソドックスなフットプリントライブラリを使用しているため、フットプリントパーツの選定ミス(もともとキツキツを前提にしていたもの??)か、PCB製造時の誤差? など調査から入ります。

koron, 2020-12-28:
PCBの製造誤差、もしくは機械特性の可能性が高そうです。

というのも右側のLED窓についても次の写真で示すようにカットの精度が悪く、角が出ていない&削り溝が残っており SK6812MINI-Eが入らなかったので削りました。写真は SW-R20 のものですが、右側に関しては全部の窓を削る必要がありました。左側はそのような必要はありませんでした。

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

hanachi-ap, 2020-12-28:
LEDのホールの件もご報告ありがとうございます。
いま手元にあるPCBでもRが見てわかるほどの削り残しは見えないので製造時の差が大きいようです。

同じ設計でも製造メーカごとに差がでるのでいい感じになるメーカーを見つけるのも大事、という先達のノウハウもありますので検討します。
ただ、たしかにスイッチの足はキツめなのでフットプリントについても見直しを行いたいと思います。

hanachi-ap, 2021-01-03:
Cherry MKの規格では 補助足の直径 1.7018mm±0.0508mm (  0.067inch±0.002)となっています。
(https://datasheet.octopart.com/MX1A-11NW-Cherry-datasheet-34676.pdf)

課題となっているrev2.0のPCBのフットプリントは 設計時1.70mmとしています。
手元の現物はおおよそ1.65~1.71程度(任意サンプリング)でしたのでとほぼ公差の範囲には入っているかとおもいます。
しかし実際には私の手持ちのスイッチでも非常にきついものがあることを確認しました。

補助時足はPCBにスイッチを固定するためのものとして考慮されているので妥当なのかもしれませんが、プレートを使用する際はマイナス効果が大きいため次のリビジョンではホールサイズを大きくするようにします。(具体的には0.175を予定)

hanachi-ap, 2021-01-03:
ビルドガイドは次のリビジョンに向けての見直しの中で吸収しますが、個別のリビジョンに対する注意事項は本文の中でなく注意事項として外部で注釈するようにしたいと思います。

koron, 2021-01-07:
穴の直径ではなく位置関係(=距離)の可能性はないでしょうか。
私の観測範囲だと両穴を外側に削ることで入るようになりました。

公差範囲内のものが3つ(中央の大足x1+小足2本)が組み合わさって
最終的に交差の範囲を超えた、みたいなことを想定しています。

Closed 2021-02-19.

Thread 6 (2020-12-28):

右側のトッププレートとPCBのアライメントがズレてる

koron, 2020-12-28:
右側のトッププレートとキースイッチを取り付けると以下の写真で示したようにキースイッチが右へ傾きます。この写真は #5 の影響も受けているのでわかりやすいかと思います。

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

トッププレートとPCBを止めているネジを外した状態で補助足のないスイッチ([Input Club Hako](https://yushakobo.jp/shop/input-club-hako-switches/) を使用)を4か所に取り付けて、トッププレートとPCBのアライメントをキースイッチベースで取ってみた写真がこちらです。

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

ネジ穴の中でスペーサーが右へズレています。以下の写真は上の写真から左上の部分を拡大したものです。

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

これによりキースイッチが正しくハマらず #5 と合わせて非常に抜けやすい状態になります。

koron, 2020-12-28:
PCB側のネジを緩めて調整したら調整できる範囲だろうか?

koron, 2020-12-28:
PCB側とトッププレート側のネジを緩めてスイッチを指したところ調整可能な範囲でした。なのでこのissueは閉じます。

しかし同じようにハマる可能性があるので「ケースの組み立て」の手順は見直したほうが良いと思います。そちらに関しては後程issueを挙げさせていただきます。

Closed 2020-12-28.

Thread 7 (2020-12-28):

ProMicroのピッソケットを挿入するホール周辺にメッキがない

hanachi-ap, 2020-12-28:
PCB裏面側ののProMicroコンスルーを挿入するホール周辺のメッキがありません。
このためProMicroとPCBの接触が悪くなり導通しないピンが生じることがまれに発生します。

コンスルーのピンをほんの少し曲げるなどして接触を増やすよにすれば解消できます。

hanachi-ap, 2020-12-28:
次のリビジョンにて、ProMicro部分は両面にメッキが出るようフットプリントを見直します。

Closed 2021-02-19.

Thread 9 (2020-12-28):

ケースの組み立て手順の修正提案

koron, 2020-12-28:
[ビルドガイド](https://github.com/hanachi-ap/willow64-doc/blob/main/buildguide-willow64-r2.md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) に書かれた手順で組み立てると #6 のようなトラブルにあうことが考えられます。それを避けるためにケース組み立ての手順を修正したほうが良いでしょう。

たとえば [Corne Cherry](https://github.com/foostan/crkbd/blob/master/corne-cherry/doc/v3/buildguide_jp.md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) だとトッププレートにスイッチを付けてからPCBに装着することを推奨しています。

> トッププレートにキースイッチに取り付けた後、キースイッチをソケットにはめ込みます。 先にすべてのキースイッチをトッププレートに取り付けてしまうと、ソケットにはめ込む難易度が上がってしまうため、先に端のキースイッチのみを取り付ける方が簡単です。

---

以下、組み立て手順の修正案

1. トッププレートとPCBを4個のスペーサーSと8個のネジSで接続する。この時ネジは緩め(抵抗を感じる程度から半回転ほど戻す程度)にする。
2. トッププレートのネジの近くの4か所にキースイッチを装着することで、トッププレートとPCBの位置を合わせをする。
3. トッププレートとPCBを繋ぐ8個のネジSを締める。
4. トッププレートに8個のスペーサーLを8個のネジSで接続する。この時ネジは緩め(抵抗を感じる程度から半回転ほど戻す程度)にする。
5. ボトムプレートを4つのネジLで手順4のスペーサのうち4つに固定する。この時ネジは緩め(抵抗を感じる程度から半回転ほど戻す程度)にする。
6. アンダーカバープレートを4つのネジLで接続する。
7. トッププレートとボトムプレートの緩めに装着したネジを適度に締める。

koron, 2020-12-28:
@hanachi-ap こんな感じに直してよければ、後日になりますがPRを出しますけどどうでしょうか?

hanachi-ap, 2020-12-28:
そんなに甘えるのも恐縮ですが、、もしよろしければお願いします

hanachi-ap, 2021-01-03:
PRの内容を確認しました。次のリビジョン向けの修正に取り込む予定です。

Closed 2021-02-19.

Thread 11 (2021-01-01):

ゴム足の取り付け位置の推奨箇所の提示が欲しい

koron, 2021-01-01:
ビルドガイドには以下のように書いてありゴム足の位置がわかる以下の写真が含まれていますが
確認できるゴム足は3つだけで4つ目の取り付け位置がわかりません。

> ゴム足を4箇所に貼り付けます。

試しにProMicro周辺に付けると若干浮く感じになるので、取り付け場所に指針が欲しいです。
なお私は[特殊なテープ](https://www.amazon.co.jp/gp/product/B07YF9L85P/)をゴム足とカバーの間に挟んで
厚みと柔らかさを稼いでます。

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

hanachi-ap, 2021-01-03:
ご提案ありがとうございます。
現在次のリビジョンの制作を行っています。ボトムプレートの形状も若干変わる予定なので、次のドキュメント改版のなかで吸収することを予定します。

備考: 製品添付のゴム足は必要最低限のものになっていますが、製作者としてはチルト/テント角をつけることでより操作性が高まると考えています。このあたりは利用者の嗜好も合わせてTIPSを盛り込もうと思います。

Closed 2021-02-19.

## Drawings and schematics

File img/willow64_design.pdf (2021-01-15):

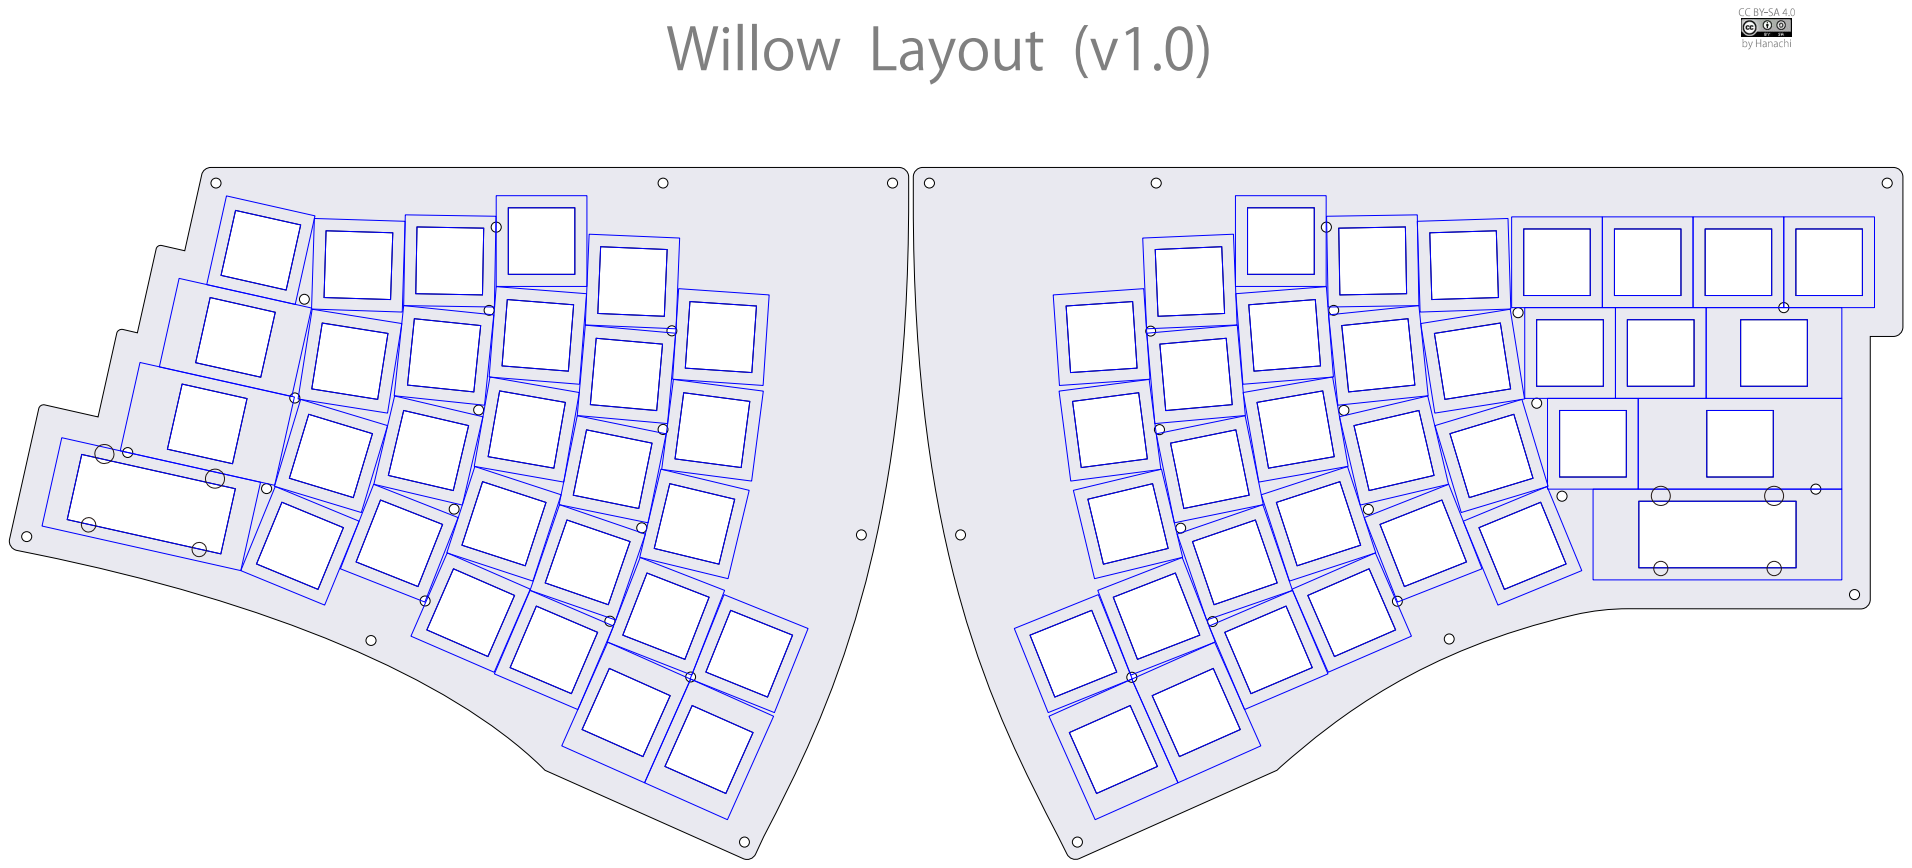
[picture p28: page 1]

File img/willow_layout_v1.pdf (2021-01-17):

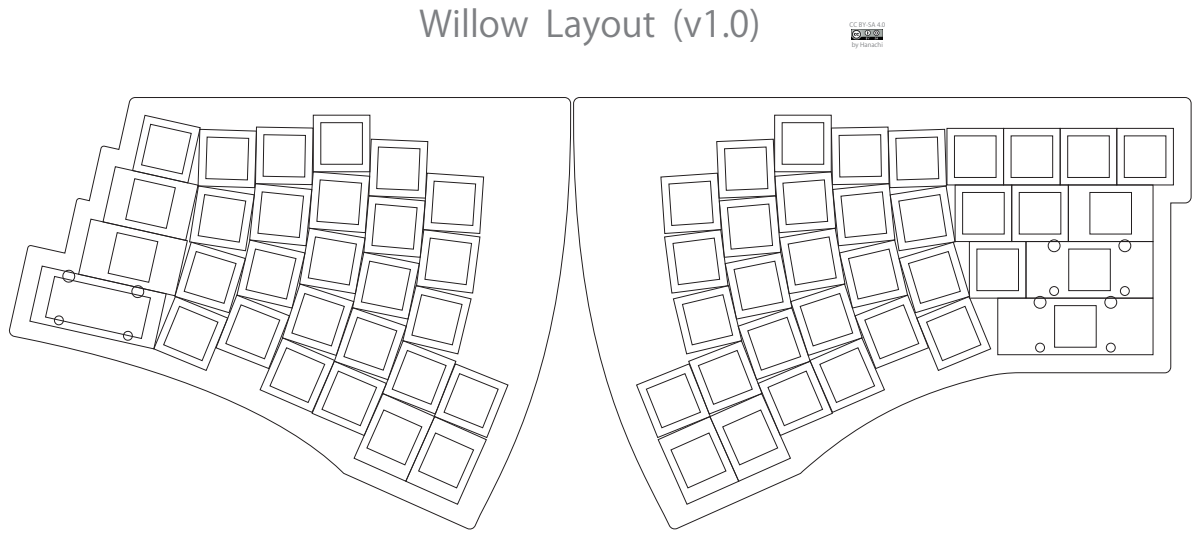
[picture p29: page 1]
by Hanachi; Willow Layout (v1.0)

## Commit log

2020-12-27 fix links in "Assembly Procedure"
2020-12-27 fix LED order indicies
2021-01-11 improve: how to build case (#12)
2021-01-11 revert to prev
    [willow64_design_rev2.2.dxf]
2021-01-17 add willow_layout images
    [willow64_design_rev2.2.dxf, willow_layout_v1.dxf]
2021-04-13 add willow_layout_dimensions.csv
    [willow_layout_dimensions.csv]
2022-07-30 add: plate data
    [willow64 bottom.dxf, willow64 cover.dxf, willow64 top.dxf]
